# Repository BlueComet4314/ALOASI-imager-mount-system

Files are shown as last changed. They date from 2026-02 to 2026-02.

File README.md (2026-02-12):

> ⚠️ This repo is under construction.

# ALOASI All-Sky Imager Mount System

## Table of Contents:

- [Cradle and Cover](#cradle-and-cover)
    - [Overview](#overview)
        - [Supported cradle variants](#supported-cradle-variants)
    - [Hardware](#hardware)
        - [Imaging Payload](#imaging-payload)
        - [Mounting Hardware](#mounting-hardware-current--planned)
    - [What's in this repo?](#whats-in-this-repo)
    - [Current Build/Design Status](#current-builddesign-status)
        - [Printable](#printable)
        - [In Progress](#in-progress)
    - [Quickstart](#quickstart)
    - [Printing Notes + Troubleshooting](#printing-notes--troubleshooting)
    - [Contributing / lab use](#contributing--lab-use)
    - [Versioning](#versioning)
- [Mounting Clamps](#mounting-clamps)

## Cradle and Cover

Mechanical design repo for the ALOASI All-Sky Imager ceiling mount hardware: CAD exports (STEP/STL), print profiles, BOMs, rail layouts, and assembly notes for the ZWO ASI183MM Pro + fisheye lens system.

### Overview

This project provides 3D-printed camera cradle options to mount a cylindrical CCD-style camera (ZWO ASI183MM Pro or similar) inside a ceiling cavity/dome while:

- avoiding scratches and pressure points
- keeping vents unobstructed
- preserving access to bottom ports/cables
- providing a stable interface to a ceiling mount/rail system

#### Supported cradle variants

Two cradle variants are maintained for different retention strategies:

- **Foam-Retained Cradle (V5 lineage)**  
  Uses foam padding on the inner walls to retain the camera. No cover required.

- **Mechanically-Locked Cradle + Cover (V7 lineage)**  
  Uses a locking cover + optional side screw mounts to rigidly retain and mount the camera (no foam required).

See `Docs/system-overview.md` for comparison and selection guidance.

### System Context

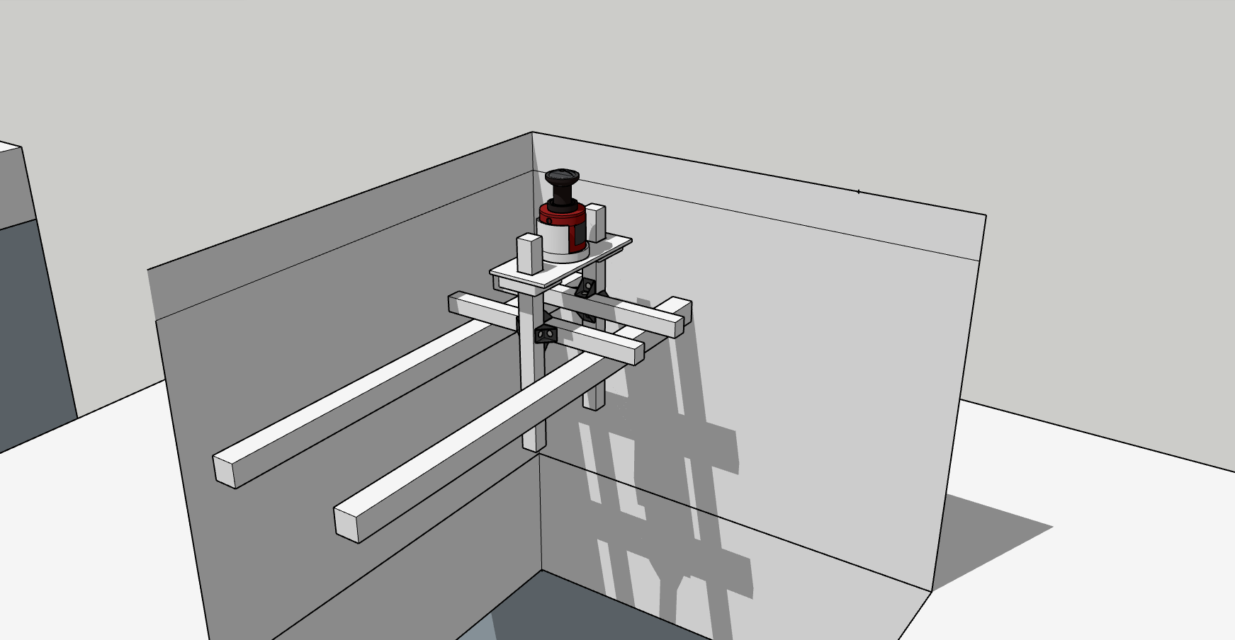
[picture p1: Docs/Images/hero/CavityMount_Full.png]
Full Cavity Mount


*Full ceiling cavity context showing rail penetration and mount location.*

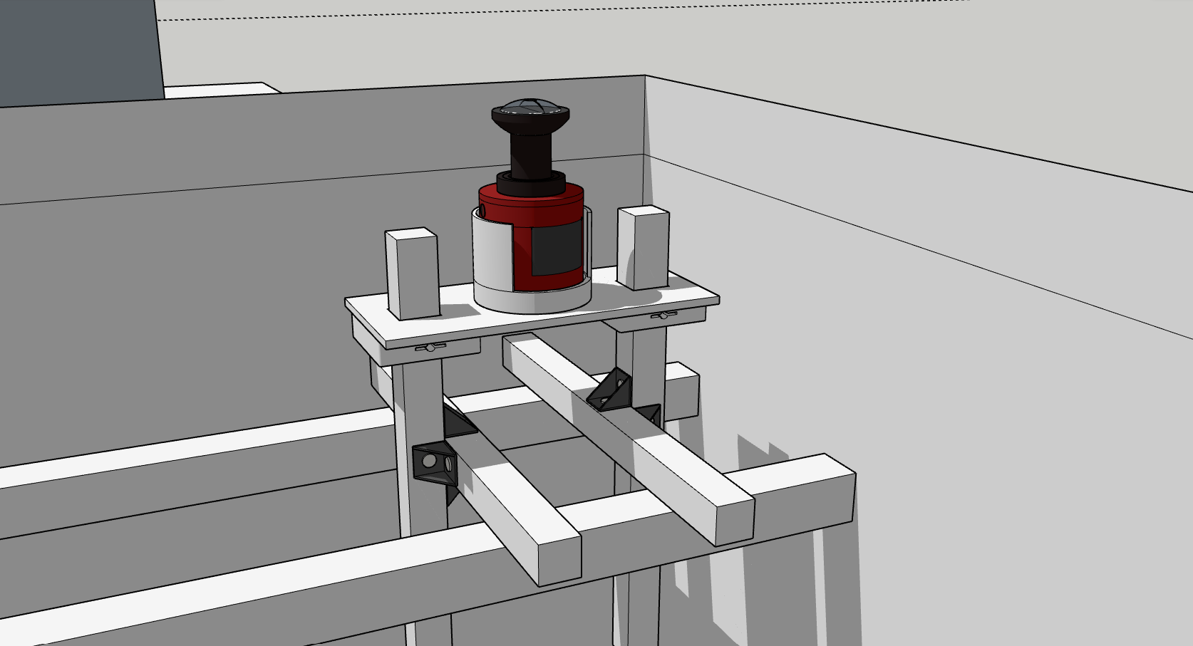
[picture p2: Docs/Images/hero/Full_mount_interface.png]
Mount Assembly


*Camera cradle mounted to board base and rail support structure.*

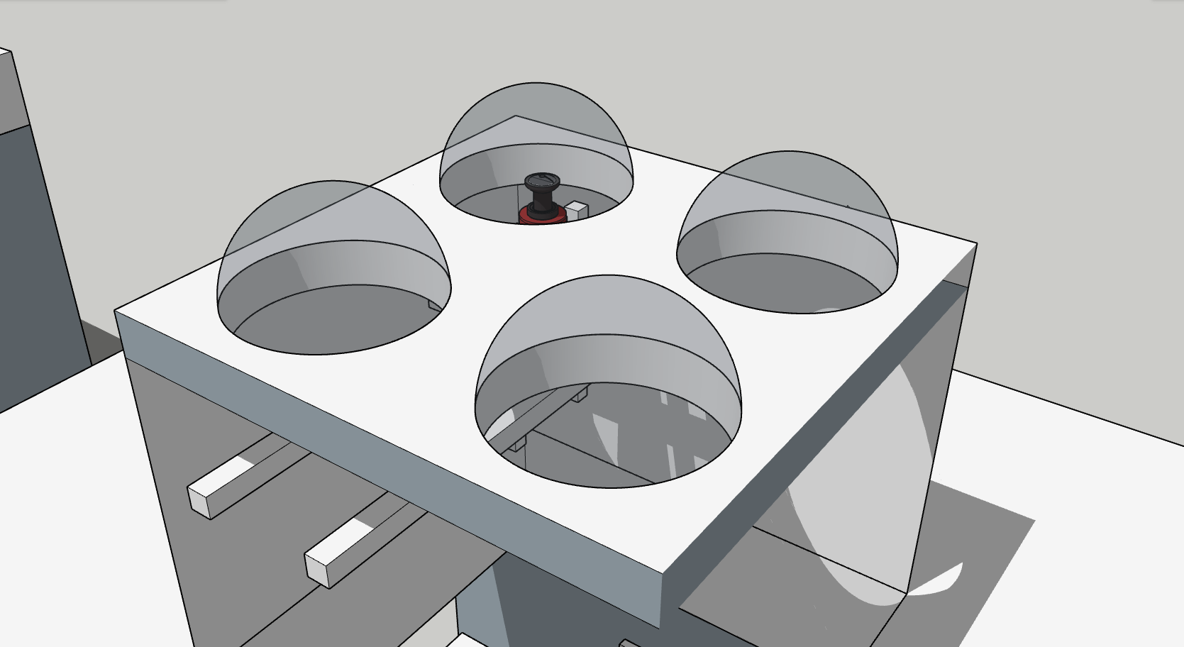
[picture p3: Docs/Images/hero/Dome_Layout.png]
Dome Aperture Layout


*Ceiling plate with multiple dome apertures used for clearance validation.*

### Hardware

#### Imaging payload
- ZWO **ASI183MM Pro**
- Fujinon **FE185C086HA** fisheye lens

#### Fabrication
- Printer: Creality K1C 3D Printer
- Materials (Cradle/Cover): Hyper-PLA (prototyping), PETG (functional)

> Material choices differ by subsystem: PETG is sufficient for the cradle/camera interface, while clamps benefit from higher stiffness/strength and humidity tolerance (Hyper-PC). 
See [`Docs/Printing/materials.md`](Docs/Printing/materials.md) for rationale and slicer notes.

#### Mounting hardware (current / planned)
- 3030 aluminum T-slot rail, 400 mm (ceiling mount frame)
- 2020 aluminum T-slot rail, 600 mm (ceiling mount frame)
- M5 and/or M6 fasteners
- Triangle brackets / corner braces
- T-nuts (match rail series)

<!-- ### Legacy / alternate
-  -->

### What’s in this repo

**Repo map:**
- [`Docs/`](Docs/)            -> how it works / how to build it
- [`releases/`](releases/)    -> print-ready exports organized by version + variant
- [`cad/`](cad/)              -> editable sources + exports (SketchUp + Onshape links/exports)
- [`lab-notes/`](lab-notes/)  -> print logs + tuning/slicer settings
- [`archive/`](archive/)      -> older iterations kept for reference

### Current build/design status

#### Printable
- **Foam-Retained Cradle (V5 lineage)**
- **Mechanically-Locked Cradle (V8 Lineage)** - Hyper PLA
- **Cover for Cradle (V4 Lineage)** - Hyper PLA

#### In progress
- **Mechanically-Locked Cradle + Cover (V7 lineage)** - PETG testing
- Side screw mounts (M5) for rigid attachment to the board base
- CR-Nylon tuning for improved slit/hex feature fidelity
- Hyper-PC tuning for improved stability and shrink

### Quickstart

1) Choose a cradle variant:
- Foam-Retained (simpler, fewer parts)
- Mechanically-Locked + Cover (more rigid, tighter tolerances)

2) Download the latest release:
- GitHub releases: [Latest Release](../../releases/latest)
- In-repo exports: [`releases/`](releases/)

3) Print:
- See [`cr-nylon.md`](Docs/Printing/cr-nylon.md) or [`Docs/Printing/`](Docs/Printing/) for material notes
- Each release includes `notes.md` with recommended orientation and settings

4) Assemble:
- See [`Docs/assembly.md`](Docs/assembly.md)

### Printing notes + troubleshooting

### Contributing / lab use

- Use clear filenames: `partname_variant_rev_material.stl`
  Example: `cradle_foam_v5_nylon.stl`
<!-- - Log print changes in `lab-notes/test-prints.md` with photo + settings delta
 -->
- Prefer releases for anything used in the lab (avoid printing from `cad/stl-scratch/`)

### Versioning

- **V5 lineage** = Foam-Retained Cradle family
- **V7 lineage** = Mechanically-Locked Cradle + Cover family

Milestones are tagged and exported under [`releases/`](releases/).

## Mounting Clamps

### Overview

### Hardware

#### Fabrication / Materials
- Prototype: Hyper-PLA
- Tested: CR-Nylon (good strength, moisture-sensitive during printing)
- Functional (current): Hyper-PC (preferred for strength + humid environments)

> Material choices differ by subsystem: PETG is sufficient for the cradle/camera interface, while clamps benefit from higher stiffness/strength and humidity tolerance (Hyper-PC).
See [`Docs/Printing/materials.md`](Docs/Printing/materials.md) for rationale and slicer notes.

### Current build/design status

#### Printable

Both designs for the clamps have been finalized:
- [LockingCollarV4-M5](releases/) - Locking collar with M5 sized screw hole and nut
- [LockingCollarV4-M6](releases/) - Locking collar with M6 sized screw hole and nut

### Quick Start

### Printing Notes + Troubleshooting
- CR-Nylon is very sensitive to moisture; drying is required for low-stringing prints.
- See [`Docs/Printing/cr-nylon.md`](Docs/Printing/cr-nylon.md) and [`lab-notes/test-prints.md`](lab-notes/test-prints.md).

### Contributing / lab use

### Versioning

### System Context

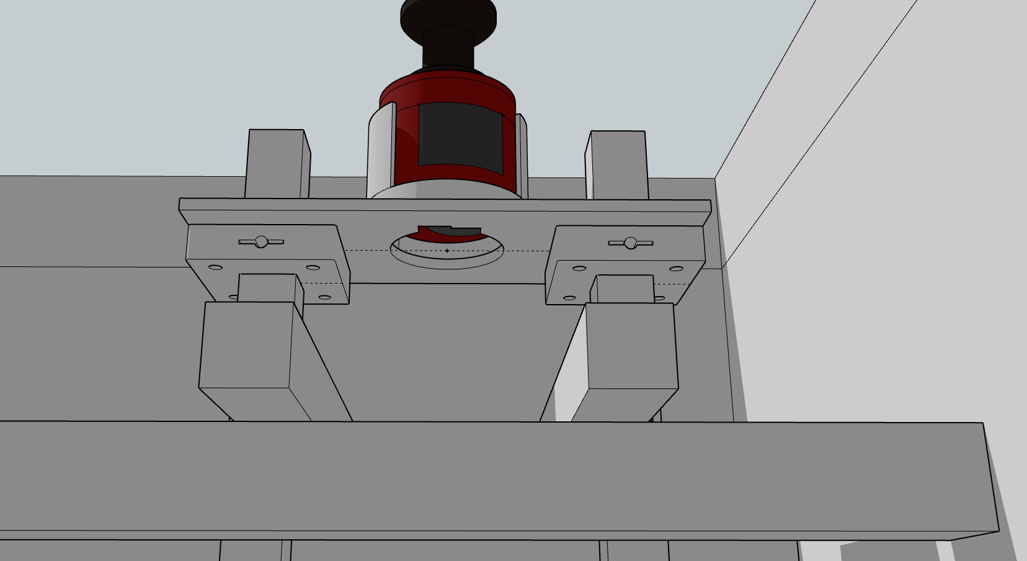
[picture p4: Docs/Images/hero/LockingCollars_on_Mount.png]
Locking Collars/Clamps

*Camera cradle mounted to board base and rail support structure. Board base is sitting on top of the clamps.*

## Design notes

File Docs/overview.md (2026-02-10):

# Cradle design breakdown (CCD camera cradle)

The cradle is intended to be printed in a semi-tough polymer (final: PETG) to create a snug, non-marring grip.

## Cradle Variants

Two cradle variants are maintained to support different installation constraints and retention philosophies.

### Foam-retained Cradle

### Mechanically-locked Cradle and Cover

\bf{Quick Comparison}
| Feature | Foam-retained | Locked Cradle |
| Retention | Foam padding | Mechanical lock + cover |
| Extra Parts | Foam pieces | cover + screws |
| Vibration resistance | Moderate | High |
| Tolerance forgiving | High | Medium |
| Best for | Quick installs, prototypes | Permanent installations |

Core geometry
1) Open-ring / partial-cylinder body

What it is:
A curved “C” shape rather than a full circular clamp around the camera.

Why:

Prevents blocking the camera’s side vents/heat dissipation

Makes install/removal easier without disassembling the whole mount

Reduces print material while maintaining structural stiffness

Design note:
The opening is wide enough to avoid creating a “full collar” that could trap heat or require forcing the camera through.

2) Inner support lip (camera seating ledge)

What it is:
A shallow ledge/rim on the inside bottom edge that the camera rests on, rather than hanging from friction alone.

Why:

Stops vertical slip

Converts load into compression on the ledge instead of relying entirely on clamping pressure

Keeps the camera stable even if foam compresses over time

Typical sizing logic:

Inner lip diameter slightly larger than camera OD for foam/padding clearance

Lip width chosen to support the camera body without covering ports

3) Clearance gap for foam/padding

What it is:
A small radial gap between camera outer diameter and cradle inner surface.

Why:

Foam prevents scratching

Foam increases friction and stabilizes the camera without hard pressure

Allows tolerance flexibility (printer variance + real camera OD variance)

Implementation:
You intentionally model the cradle inner diameter slightly larger than the camera OD and rely on foam to take up the difference.

Cooling and cable features
4) Vent-safe cutout / incomplete coverage

What it is:
The cradle does not fully wrap the camera, and the covered regions are positioned so they do not obstruct vents.

Why:

The ASI183MM Pro uses body conduction + airflow

Blocking vents increases thermal noise and can cause long-term heat stress

5) Bottom cable/port pass-through (large center hole)

What it is:
A wide cutout in the cradle base directly under the camera’s bottom face.

Why:

Prevents interference with:

USB/power ports

any protruding connectors

the camera’s fan/vent area (if present)

Allows cables to route downward without sharp bends

Design note:
This hole is intentionally oversized so the cradle never becomes the limiting factor for cable clearance.

6) Optional cable notch(es)

What it is:
Small cutouts on the lower edge that act like “cable exits.”

Why:
Even with a big center hole, some connectors need a specific route path. Notches prevent cables from being pinched between cradle and mount.

Mechanical interface features
7) Flat mounting faces / tabs / attachment points

What it is:
Areas designed for connecting the cradle to a larger mount:

flat pads

bolt holes

or alignment faces

Why:

Provides a repeatable interface to the ceiling mount

Prevents rotation around the camera axis

Gives the cradle a stable way to transfer load into rails/plates

8) Chamfered edges (comfort + print + stress relief)

What it is:
Small chamfers on sharp edges, especially at:

top rim

lip edges

mounting pads

Why:

Prevents sharp edges from digging into foam

Reduces stress concentration (cracks start at sharp corners)

Helps prints come off cleaner and reduces elephant-foot sensitivity

Print intent and materials
9) Print orientation (typical)

Usually oriented so the curved body prints with good layer continuity. The cradle should be oriented to minimize support inside critical surfaces (the inner wall that contacts foam).

Goal:
Keep the inner “contact surface” smooth and dimensionally stable.

10) Material choice logic

PLA: good for fast geometry checks, but brittle and creeps over time

CR-Nylon (final): tough, fatigue-resistant, better for clamps/holding parts

ABS possible, but nylon typically wins for long-term mechanical grip

What’s “tunable” (parameters you may change later)

If you need iterative updates, these are the “knobs”:

Camera OD (dominates inner diameter)

Foam thickness (controls clearance)

Lip height (how “captured” the camera is)

Lip width (support area vs port clearance)

Bottom hole diameter (cable clearance)

Opening angle of the cradle (more open = less heat trapping, easier install)

Mount hole pattern (depends on rail system)

Wall thickness (strength vs print time)

Validation checklist (what “success” looks like)

When physically tested, the cradle should:

allow the camera to drop in without force

sit on the inner lip without wobble

not cover vents

allow all cables to connect and bend comfortably

not rotate under light handling

feel secure once foam is installed

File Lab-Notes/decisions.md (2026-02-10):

# 1. Maintain two cradle variants

- Foam-retained cradle (V5) performed well and remains valid for simpler installs.
- Locking cradle (V7) introduced to enable rigid mounting and eliminate reliance on foam, at the cost of tighter tolerances and additional parts.
- Both are retained to support different installation constraints.

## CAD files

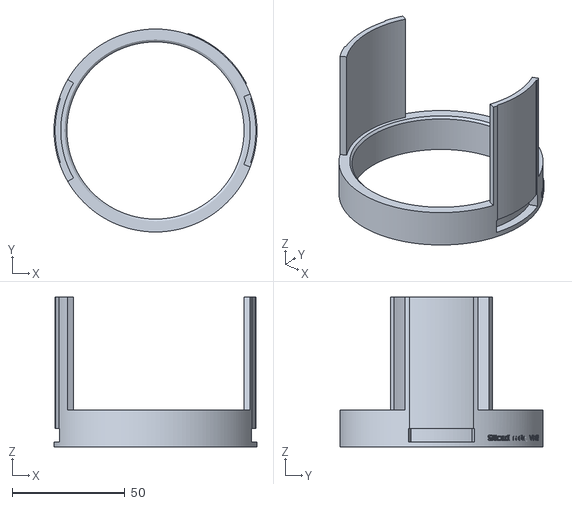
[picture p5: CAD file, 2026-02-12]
CAD/locked-cradle/validation/lock-slice_cradlev8.2.stl
90.0 x 90.0 x 66.5

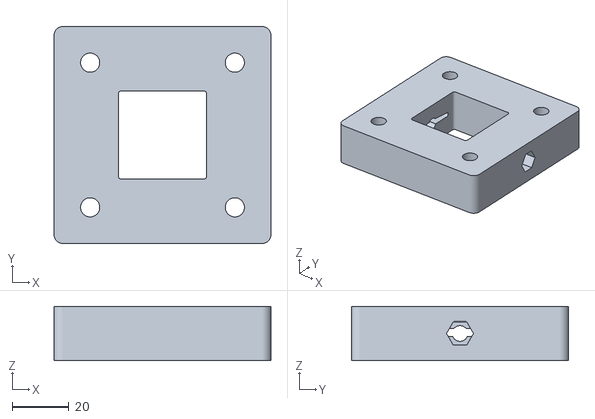
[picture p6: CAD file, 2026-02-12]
Releases/v4.5/locking-collar/M5Locking_CollarV4.3.stl
76.2 x 76.2 x 19.1

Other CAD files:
Releases/v4.5/locking-collar/M6Locking_CollarV4.4.stl

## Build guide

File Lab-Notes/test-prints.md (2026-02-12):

# Mechanically-Locked Cradle

## v8.1 - Improvement on Locking Mechanism

Goal: Improve snap and removal force

Changes:
- Added slight indent along cradle outer walls

## v8.2 – Locking Mechanism Slice Test 3

Goal:
Continue validate tab engagement + cover snap force without printing full body.

Changes:
- Removed chamfer from outer lip of hole (the Lock)
- Reduced interference on inner lip

Result:
- Engagement improved
- Insert and removal force improved

# Cover for Cradle

## v4.2 - Improved Latch dimensions

Changes:
- Increased latch width slightly.

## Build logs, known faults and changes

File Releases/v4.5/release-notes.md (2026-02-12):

## System Release

### Included components:
- Cradle v8.3
- Cover v4.3
- M5 Locking Collar v4.3
- M6 Locking Collar v4.4

### Compatibility:
These parts were validated together on 3030 rail frame.

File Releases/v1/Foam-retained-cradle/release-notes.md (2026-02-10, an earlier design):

<!-- Include:

Purpose: passive retention with foam padding

Mounting: rests in cradle, no cover required

Pros:

fewer parts

easier print

tolerates slight dimensional error

Cons:

foam wear

less rigid under vibration

Recommended material: PETG / ABS / Nylon

Print orientation + infill notes

Internal version lineage:
Derived from Cradle V5 -->

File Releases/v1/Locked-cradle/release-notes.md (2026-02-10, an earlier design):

<!-- Include:

Purpose: rigid mounting + mechanical retention

Requires:

side screw mounting

cover component

Pros:

no consumables (foam)

more rigid and repeatable

Cons:

more parts

tighter tolerances

Print notes for:

cradle body

cover

Internal version lineage:
Derived from Cradle V7 -->

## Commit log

2026-01-21 Add .gitignore for CAD + slicer files
2026-02-10 Initial repo structure and documentation
    - Add README with system overview and cradle variants
    - Establish folder structure for docs, CAD, releases, and lab notes
    - Add printable foam-retained cradle (V5 lineage)
2026-02-12 Refined README, updated build/design status. Added latest stl models to releases folder (Locked-Cradle_V8.3, Locked-Cover_V4.3, M5LockingColar_V4.3, and M6LockingColar_V4.4.
    [M5Locking_CollarV4.3.stl, M6Locking_CollarV4.4.stl, lock-slice_cradlev8.2.stl]
